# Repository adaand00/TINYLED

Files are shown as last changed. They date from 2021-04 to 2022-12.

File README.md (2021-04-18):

# TINYLED

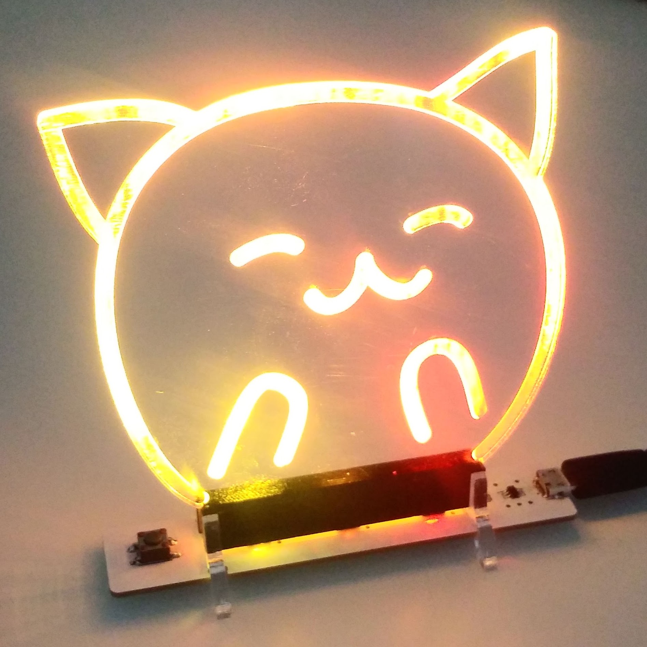
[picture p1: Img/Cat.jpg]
Image of cat sign


Light-up sign with an attiny10 and three ws2812b RGB LEDs. 

## Introduction

This is a simple project to make a light-up stand for laser-cut acrylic signs. I mainly did this as an excercise in using the attiny10-series of microcontrollers. They are very limited with just 512 or 1024 bytes of flash and 32 bytes RAM. The final code is just under 500 bytes, of which half is for driving the LEDs. 

## Circuit board

The PCB was designed in fusion360. There are test points on the underside for pogo-pin programming. The PCB also has slots for the laser cut feet to snap-fit into. 

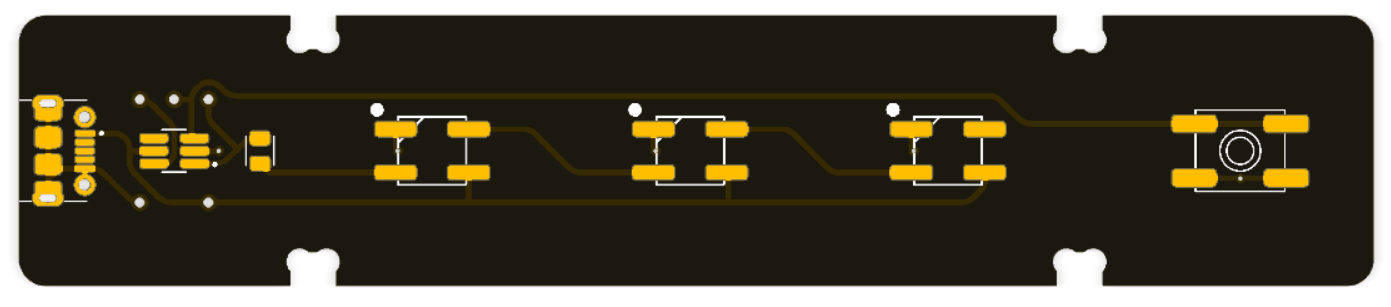
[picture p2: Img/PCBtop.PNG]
Top of PCB

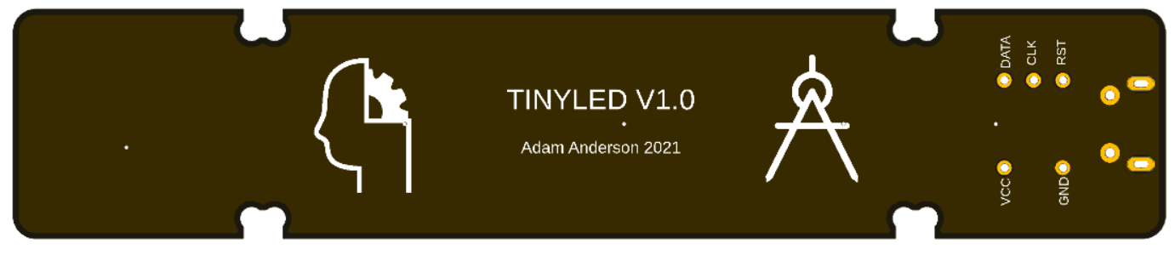
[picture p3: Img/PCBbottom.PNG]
Bottom of PCB


Gerber files are supplied in the hardware folder. 

## Programming

I used the [Attiny10IDE](https://github.com/wholder/ATTiny10IDE) by @wholder to program the chip. I managed to fit one rainbow animation and a couple solid color animations into the 512 byte memory of the attiny5. Because of space constraints, I have only implemented hue control for the LEDs. If the code was optimized a bit, brightness control could perhaps also be implemented, which would enable some more cool animations. 

The source code is provided as a .c file that can be modified and built with the attiny10IDE. There is also a .ino file that can be used to turn an arduino into a programmer.

## BOM

* 1x Attiny4/5/9/10 (tested with 5, should work with all)
* 3x ws2812b, also known as neopixels
* 1x 6x6mm tactile pushbutton with SMD mounting
* 1x 500 ohm 0603 resistor
* 1x molex 105017-0001 micro USB connector 
* 1x PCB 

## Future work

- [ ] Add brightness control in LED driver function.
- [ ] Modify PCB to allow for bigger signs (Move feet, add more LEDs, use smaller switch).
- [ ] Ditch micro USB for battery, USB-C or barrel jack.

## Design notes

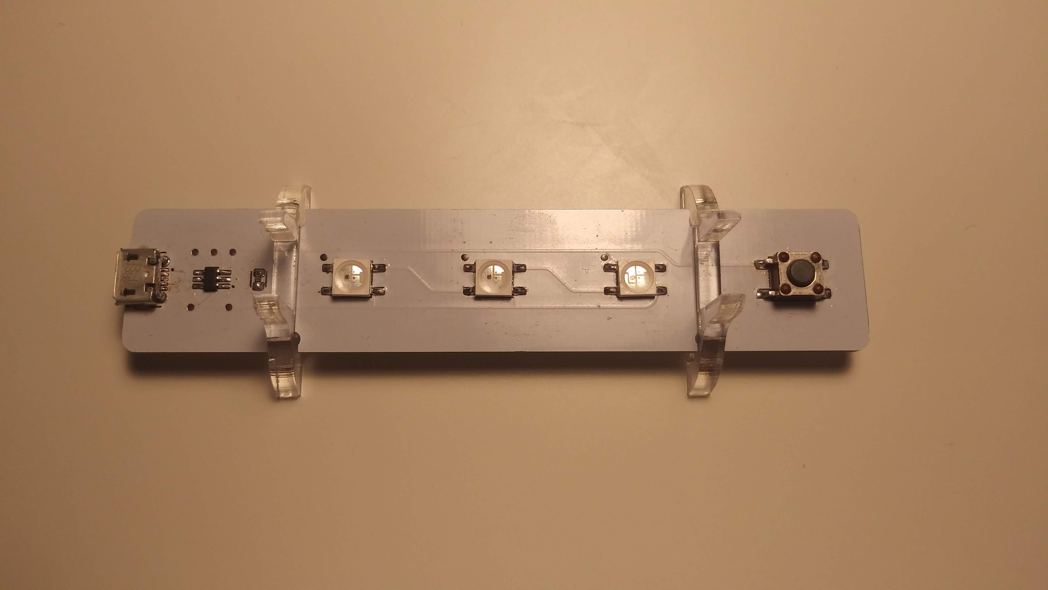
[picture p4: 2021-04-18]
Img/PCB.jpg

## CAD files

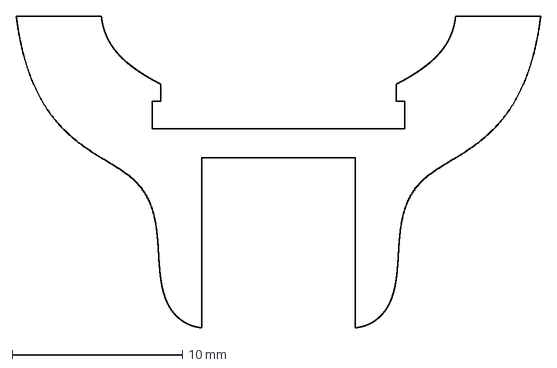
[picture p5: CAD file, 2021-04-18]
Hardware/Legs_laser.dxf
30.8 x 18.3 mm

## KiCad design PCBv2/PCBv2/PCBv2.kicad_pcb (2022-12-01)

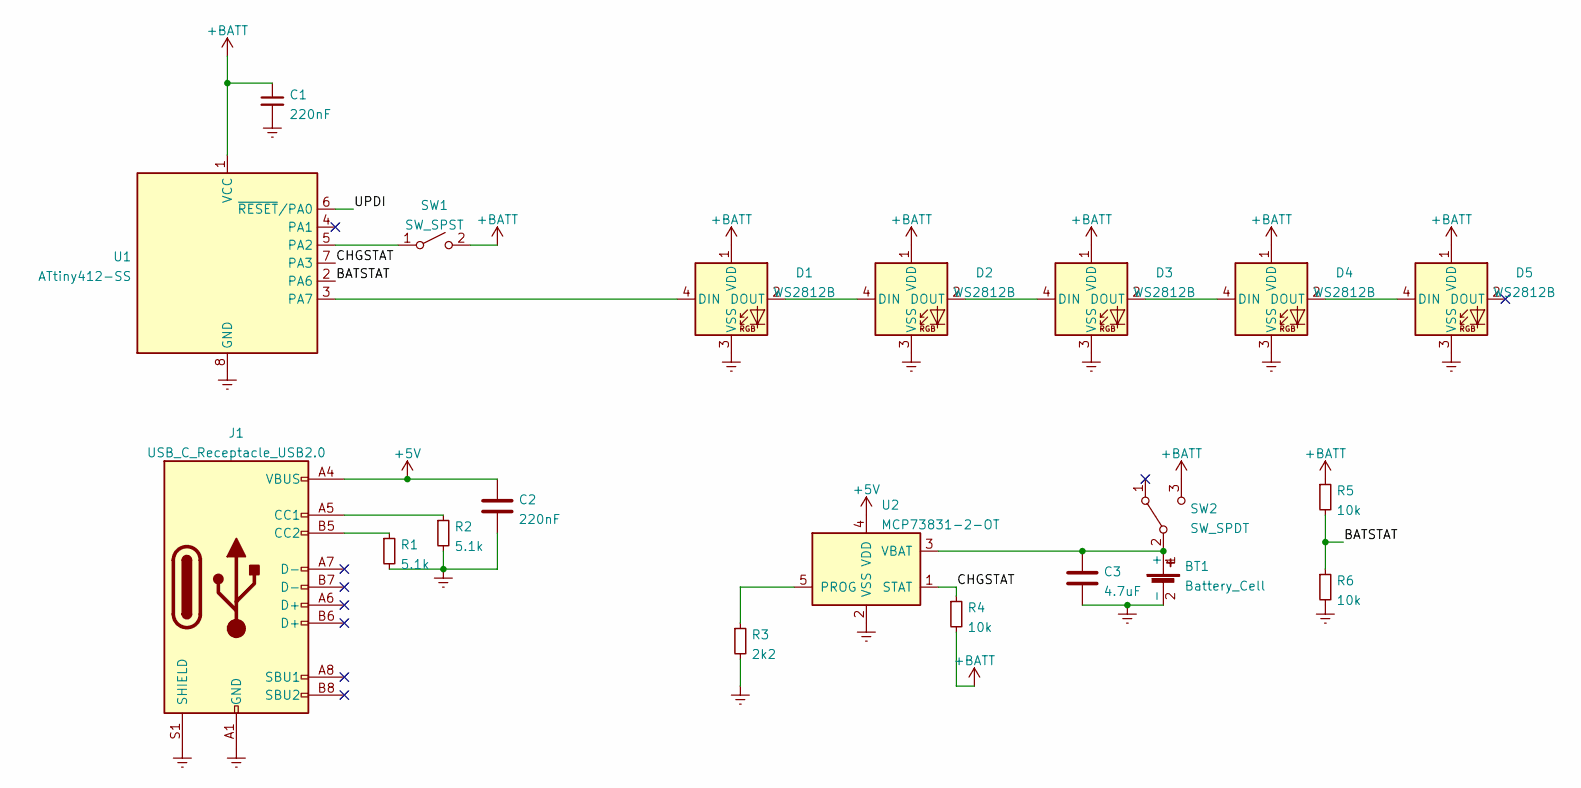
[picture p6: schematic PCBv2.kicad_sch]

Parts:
BT1: Battery_Cell; CB-18650-PC2
C1, C2: 220nF; C_0603_1608Metric_Pad1.08x0.95mm_HandSolder
C3: 4.7uF; C_1206_3216Metric_Pad1.33x1.80mm_HandSolder
D1, D2, D3, D4, D5: WS2812B; LED_WS2812B_PLCC4_5.0x5.0mm_P3.2mm
J1: USB_C_Receptacle_USB2.0; USB_C_Receptacle_HRO_TYPE-C-31-M-12
R1, R2: 5.1k; R_0603_1608Metric_Pad0.98x0.95mm_HandSolder
R3: 2k2; R_0603_1608Metric_Pad0.98x0.95mm_HandSolder
R4, R5, R6: 10k; R_0603_1608Metric_Pad0.98x0.95mm_HandSolder
SW1: SW_SPST; SW_Push_1P1T_NO_6x6mm_H9.5mm
SW2: SW_SPDT; SW_SPDT_CK-JS102011SAQN
U1: ATtiny412-SS; SOIC-8_3.9x4.9mm_P1.27mm
U2: MCP73831-2-OT; SOT-23-5

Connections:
+5V: C2.1, J1.A4 (VBUS), J1.A9 (VBUS), J1.B4 (VBUS), J1.B9 (VBUS), U2.4 (VDD)
+BATT: C1.1, D1.1 (VDD), D2.1 (VDD), D3.1 (VDD), D4.1 (VDD), D5.1 (VDD), R4.2, R5.1, SW1.2 (B), SW2.3 (C), U1.1 (VCC)
/BATSTAT: R5.2, R6.1, U1.2 (PA6)
/CHGSTAT: R4.1, U1.7 (PA3), U2.1 (STAT)
/UPDI: U1.6 (~RESET/PA0)
Earth: BT1.2 (-), C1.2, C2.2, C3.2, D1.3 (VSS), D2.3 (VSS), D3.3 (VSS), D4.3 (VSS), D5.3 (VSS), J1.A1 (GND), J1.A12 (GND), J1.B1 (GND), J1.B12 (GND), J1.S1 (SHIELD), R1.2, R2.2, R3.2, R6.2, U1.8 (GND), U2.2 (VSS)
unnamed: BT1.1 (+), C3.1, SW2.2 (B), U2.3 (VBAT)
unnamed: D1.2 (DOUT), D2.4 (DIN)
unnamed: D1.4 (DIN), U1.3 (PA7)
unnamed: D2.2 (DOUT), D3.4 (DIN)
unnamed: D3.2 (DOUT), D4.4 (DIN)
unnamed: D4.2 (DOUT), D5.4 (DIN)
unnamed: J1.A5 (CC1), R2.1
unnamed: J1.B5 (CC2), R1.1
unnamed: R3.1, U2.5 (PROG)
unnamed: SW1.1 (A), U1.5 (PA2)

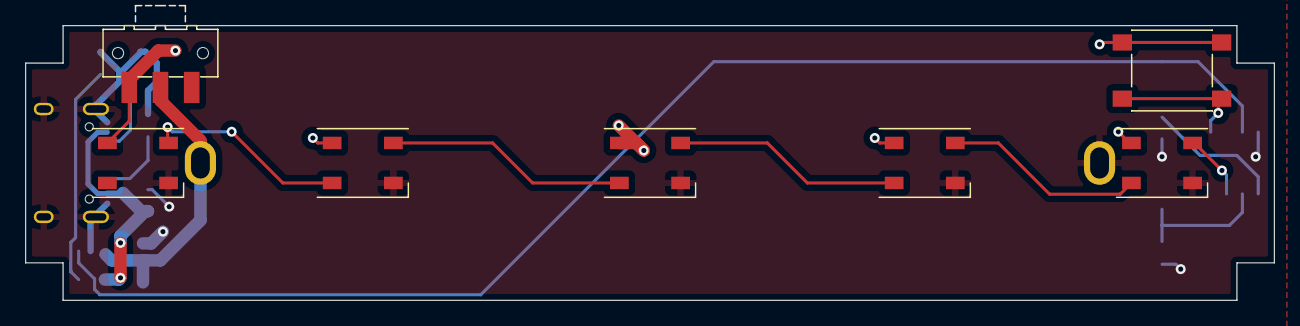
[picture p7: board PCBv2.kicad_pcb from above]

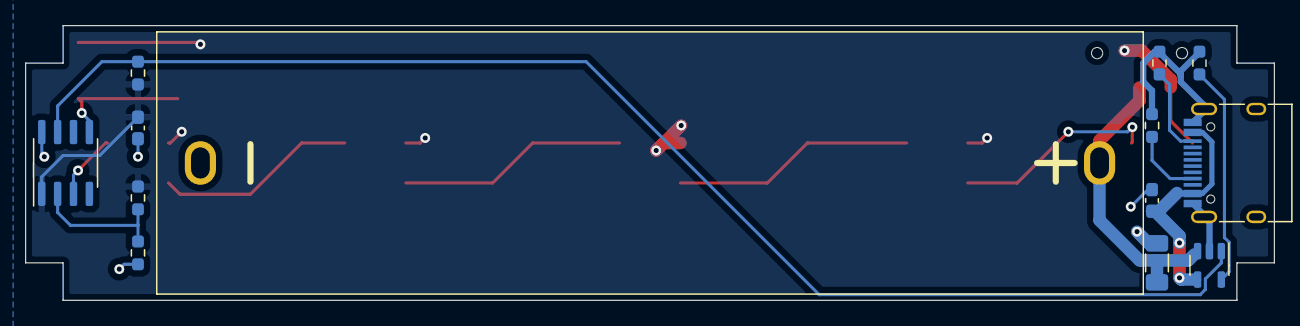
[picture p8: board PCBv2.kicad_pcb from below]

Board: 2 copper layers, 100.0 x 22.0 mm, 20 parts (13 on the bottom side), 15 nets.

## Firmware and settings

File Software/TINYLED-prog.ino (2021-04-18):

#include <avr/io.h>

/*
 * ATtiny10 TPI Generated Programmer for ATTiny10IDE.  Supports both 5V and 12V Programmers
 * IMPORTANT: Original, Relay-based Emulator/Programmer board needs mod (A0 tied to ground)
 */
 
//                 +-\/-+
//  TPIDAT / PB0 1 |    | 6 PB3 / RESET
//           Gnd 2 |    | 5 Vcc
//  TPICLK / PB1 3 |    | 4 PB2
//                 +----+

const unsigned char program[] PROGMEM  = { 
  0x14, 0xC0, 0x23, 0xC0, 0x22, 0xC0, 0x21, 0xC0, 0x20, 0xC0, 0x1F, 0xC0, 0x1E, 0xC0, 0x1D, 0xC0,
  0x1C, 0xC0, 0x1B, 0xC0, 0x1A, 0xC0, 0xA4, 0xC0, 0x9D, 0xC0, 0x9C, 0xC0, 0x9D, 0xC0, 0x9E, 0xC0,
  0x9D, 0xC0, 0x9E, 0xC0, 0x97, 0xC0, 0x96, 0xC0, 0x97, 0xC0, 0x11, 0x27, 0x1F, 0xBF, 0xCF, 0xE5,
  0xD0, 0xE0, 0xDE, 0xBF, 0xCD, 0xBF, 0x20, 0xE0, 0xA0, 0xE4, 0xB0, 0xE0, 0x01, 0xC0, 0x1D, 0x93,
  0xA6, 0x34, 0xB2, 0x07, 0xE1, 0xF7, 0x02, 0xD0, 0xBC, 0xC0, 0xDA, 0xCF, 0x48, 0xED, 0x4C, 0xBF,
  0x16, 0xBF, 0x08, 0x9A, 0x09, 0x98, 0x42, 0xE0, 0x43, 0xB9, 0x41, 0xE0, 0x41, 0xA9, 0x15, 0xA9,
  0x20, 0xE8, 0x30, 0xE0, 0x01, 0x99, 0x0A, 0xC0, 0x45, 0xA1, 0x41, 0x13, 0x08, 0xC0, 0x12, 0xA9,
  0x41, 0xA1, 0x4F, 0x5F, 0x41, 0xA9, 0x41, 0xE0, 0x45, 0xA9, 0x01, 0xC0, 0x15, 0xA9, 0x41, 0xA1,
  0x41, 0x13, 0x0C, 0xC0, 0x48, 0xE4, 0x10, 0x9A, 0x00, 0x00, 0x10, 0x98, 0x00, 0x00, 0x00, 0x00,
  0x00, 0x00, 0x00, 0x00, 0x00, 0x00, 0x41, 0x50, 0xB1, 0xF7, 0x2E, 0xC0, 0x41, 0x30, 0x51, 0xF4,
  0x42, 0xA1, 0x51, 0xE0, 0x54, 0x0F, 0x52, 0xA9, 0x5B, 0xE0, 0x54, 0x0F, 0x53, 0xA9, 0x4B, 0x5E,
  0x44, 0xA9, 0x22, 0xC0, 0x4E, 0x30, 0xF8, 0xF4, 0x42, 0x50, 0x42, 0x95, 0x40, 0x7F, 0x50, 0xA1,
  0x65, 0x2F, 0x70, 0xE0, 0x57, 0xFF, 0x06, 0xC0, 0x80, 0xE0, 0x91, 0xE0, 0x86, 0x1B, 0x97, 0x0B,
  0x68, 0x2F, 0x79, 0x2F, 0x83, 0xE0, 0x75, 0x95, 0x67, 0x95, 0x8A, 0x95, 0xE1, 0xF7, 0x74, 0x2F,
  0x76, 0x0F, 0x72, 0xA9, 0x78, 0xE0, 0x74, 0x0F, 0x73, 0xA9, 0x40, 0x5F, 0x46, 0x1B, 0x44, 0xA9,
  0x5E, 0x5F, 0x50, 0xA9, 0x01, 0xC0, 0x11, 0xA9, 0x41, 0xA1, 0x41, 0x13, 0x0A, 0xC0, 0x9F, 0xEB,
  0x44, 0xED, 0x51, 0xE0, 0x91, 0x50, 0x40, 0x40, 0x50, 0x40, 0xE1, 0xF7, 0x00, 0xC0, 0x00, 0x00,
  0xA9, 0xCF, 0xE2, 0xE4, 0xF0, 0xE0, 0xAE, 0x2F, 0xBF, 0x2F, 0x40, 0x81, 0x40, 0x3C, 0x10, 0xF0,
  0x40, 0x5C, 0x40, 0x83, 0xEF, 0x5F, 0xFF, 0x4F, 0x8C, 0x91, 0xB8, 0x2F, 0xB2, 0x95, 0xB6, 0x95,
  0xB7, 0x70, 0x88, 0x0F, 0x88, 0x0F, 0x88, 0x0F, 0x90, 0xE0, 0xA8, 0x2F, 0xA0, 0x95, 0x4B, 0x2F,
  0x49, 0x0F, 0x50, 0xE0, 0x4A, 0x30, 0x51, 0x07, 0x48, 0xF4, 0x45, 0x5F, 0x5F, 0x4F, 0x4F, 0x93,
  0x5F, 0x93, 0x08, 0x95, 0xCF, 0xEF, 0x05, 0xC0, 0xCA, 0x2F, 0x03, 0xC0, 0xC0, 0xE0, 0x01, 0xC0,
  0xC8, 0x2F, 0x40, 0xE0, 0x50, 0xE0, 0xD0, 0xE0, 0x62, 0x2F, 0x73, 0x2F, 0x04, 0x2F, 0x02, 0xC0,
  0x75, 0x95, 0x67, 0x95, 0x0A, 0x95, 0xE2, 0xF7, 0x6C, 0x23, 0x7D, 0x23, 0x67, 0x2B, 0x49, 0xF0,
  0x10, 0x9A, 0x00, 0x00, 0x00, 0x00, 0x00, 0x00, 0x00, 0x00, 0x00, 0x00, 0x10, 0x98, 0x00, 0x00,
  0x08, 0xC0, 0x10, 0x9A, 0x00, 0x00, 0x10, 0x98, 0x00, 0x00, 0x00, 0x00, 0x00, 0x00, 0x00, 0x00,
  0x00, 0x00, 0x4F, 0x5F, 0x5F, 0x4F, 0x48, 0x30, 0x51, 0x07, 0xF1, 0xF6, 0x9E, 0x5F, 0x96, 0x30,
  0x09, 0xF0, 0xC5, 0xCF, 0x85, 0xE4, 0x90, 0xE0, 0x8E, 0x17, 0x9F, 0x07, 0x09, 0xF0, 0xAB, 0xCF,
  0x9E, 0xCF, 0xF8, 0x94, 0xFF, 0xCF };
const unsigned char clockCal[] PROGMEM = {
 0x0A, 0xC0, 0x18, 0x95, 0x18, 0x95, 0x18, 0x95, 0x18, 0x95, 0x18, 0x95, 0x18, 0x95, 0x18, 0x95,
 0x18, 0x95, 0x18, 0x95, 0x18, 0x95, 0x00, 0xE0, 0x0E, 0xBF, 0x0F, 0xE5, 0x0D, 0xBF, 0x08, 0xED,
 0x0C, 0xBF, 0x00, 0xE0, 0x06, 0xBF, 0x05, 0xE9, 0x09, 0xBF, 0x0D, 0xE0, 0x01, 0xB9, 0x0D, 0xE0,
 0x02, 0xB9, 0x00, 0xE4, 0x0E, 0xBD, 0x0C, 0xE0, 0x0D, 0xBD, 0x0A, 0xE7, 0x07, 0xBD, 0x02, 0xE1,
 0x06, 0xBD, 0x18, 0xE0, 0x20, 0xE0, 0x22, 0x0F, 0x08, 0xD0, 0xD9, 0xF3, 0x00, 0x34, 0x08, 0xF0,
 0x23, 0x95, 0x1A, 0x95, 0xC1, 0xF7, 0x29, 0xBF, 0xF4, 0xCF, 0x01, 0x99, 0xFE, 0xCF, 0x01, 0xE0,
 0x01, 0x99, 0x08, 0x95, 0x03, 0x95, 0xE1, 0xF7, 0x01, 0x9B, 0xFE, 0xCF, 0x08, 0x95
};
const char          progName[] = "TINYLED.c";
const unsigned char progParms[]  = {  };
unsigned int        progSize;
unsigned char       flashMem[1024];
char                inbuf[8];
unsigned char       fuse = 0x0F;
boolean             hv1Mode = false;
boolean             hv2Mode = false;

#define  BIT_TIME  1
// Definitons for 5V Programmer
#define  VCC        2   // Pin 5 on ATtiny10
#define  TPICLK     3   // Pin 3 on ATtiny10
#define  TPIDAT     4   // Pin 1 on ATtiny10
#define  RESET      5   // Pin 6 on ATtiny10
#define  GND        6   // Pin 2 on ATtiny10
// Definitons for 12V Programmer (just different names for pins)
#define  SHDN       5   // 0 to turn on 12V, 1 to disable
#define  RELAY      6   // 1 to program, 0 to emulate
// Definitions for pins used to detect HV programmers
#define  HV1_DETECT A0  // Is LOW if HV Programmer (version 1, 2x DPDT relays)
#define  HV2_DETECT A1  // Is LOW if HV Programmer (version 2, 4 ch analog switch)

// Define IO Registers
#define  NVMCMD  0x33
#define  NVMCSR  0x32

// Define NVM Commands
#define  NO_OPERATION  0x00
#define  CHIP_ERASE    0x10
#define  SECTION_ERASE 0x14
#define  WORD_WRITE    0x1D

void setup () {
  // Check for HV Progammerw (HV1_DETECT or HV2_DETECT pin is LOW)
  pinMode(HV1_DETECT, INPUT_PULLUP);
  pinMode(HV2_DETECT, INPUT_PULLUP);
  delay(10);
  hv1Mode = digitalRead(HV1_DETECT) == LOW;
  hv2Mode = digitalRead(HV2_DETECT) == LOW;
  // Set flashMem to unprogrammed value and then copy program code into it
  memset(flashMem, 0xFF, sizeof(flashMem));
  memcpy_P(flashMem, program, sizeof(program));
  progSize = sizeof(program);
  Serial.begin(115200);
  disablePins();
  if (hv1Mode || hv2Mode) {
    pinMode(SHDN, OUTPUT);        // Connect SHDN
    if (hv1Mode) {
        digitalWrite(SHDN, HIGH); // 12v off
    } else {
        digitalWrite(SHDN, LOW);  // 12v off
    }
    pinMode(RELAY, OUTPUT);       // Connect RELAY
    digitalWrite(RELAY, LOW);     // Chip in Emulate mode (Relay Off)
    Serial.print("\x06\x06");     // Send ACK ACK sequence tp signal ready
  } else {
    pinMode(GND, OUTPUT);         // Connect GND
    digitalWrite(GND, LOW);       // GND Always Low
    if (sizeof(program) > 0) {
      printInstructions();
    } else {
      Serial.print("\x06\x06");   // Send ACK ACK sequence tp signal ready
    }
  }
}

void enablePins () {
  if (hv1Mode || hv2Mode) {
    digitalWrite(RELAY, HIGH);    // Chip in Program mode (Relay On)
    delay(200);
  }
  pinMode(VCC, OUTPUT);           // Connect VCC
  digitalWrite(VCC, LOW);         // VCC off
  pinMode(TPICLK, OUTPUT);        // Connect TPICLK
  digitalWrite(TPICLK, HIGH);     // Clk high
  pinMode(TPIDAT, INPUT);         // Connect TPIDAT
  digitalWrite(TPIDAT, HIGH);     // Enable pullup
  delay(10);
  if (!hv1Mode && !hv2Mode) {
    pinMode(RESET, OUTPUT);       // Connect RESET
    digitalWrite(RESET, HIGH);    // RESET Off
  }
  delay(200);
}

void disablePins () {
  pinMode(TPICLK, INPUT);       // Disconnect TPICLK
  pinMode(TPIDAT, INPUT);       // Disconnect TPIDAT
  pinMode(VCC, INPUT);          // Disconnect VCC
  digitalWrite(TPICLK, LOW);    // No pull up
  digitalWrite(TPIDAT, LOW);    // No pull up
  digitalWrite(VCC, LOW);       // No pull up
  if (hv1Mode || hv2Mode) {
    digitalWrite(RELAY, LOW);   // Chip in Emulate mode
  } else {
    pinMode(RESET, INPUT);      // Disconnect RESET
    digitalWrite(RESET, LOW);   // No pull up
  }
  delay(200);
}

void pulseClock () {
  digitalWrite(TPICLK, LOW);
  delayMicroseconds(BIT_TIME);
  digitalWrite(TPICLK, HIGH);
  delayMicroseconds(BIT_TIME);
}

void sendFrame (unsigned char data) {
  unsigned char tmp = data;
  // Write start bit
  pinMode(TPIDAT, OUTPUT);
  digitalWrite(TPIDAT, LOW);
  pulseClock();
  unsigned char check = 0;
  // Write data bits
  for (unsigned char ii = 0; ii < 8; ii++) {
    digitalWrite(TPIDAT, tmp & 1);
    check ^= tmp & 1;
    tmp >>= 1;
    pulseClock();
  }
  // Write check bit
  digitalWrite(TPIDAT, check);
  pulseClock();
  // Write stop bits
  digitalWrite(TPIDAT, HIGH);
  pulseClock();
  pinMode(TPIDAT, INPUT);
  pulseClock();
}

unsigned char readBit () {
  digitalWrite(TPICLK, LOW);
  delayMicroseconds(BIT_TIME);
  unsigned char data = digitalRead(TPIDAT) ? 1 : 0;
  digitalWrite(TPICLK, HIGH);
  delayMicroseconds(BIT_TIME);
  return data;
}

unsigned char readFrame () {
  pinMode(TPIDAT, INPUT);
  for (int ii = 0; ii < 256; ii++) {
    if (readBit() == 0) {
      // Start bit found
      unsigned char data = 0;
      unsigned char check = 0;
      for (unsigned char jj = 0; jj < 8; jj++) {
        unsigned char tmp = readBit();
        data >>= 1;
        data |= tmp != 0 ? 0x80 : 0x00;
        check ^= tmp & 1;
      }
      unsigned char tmp = readBit();
      readBit();
      readBit();
      if (tmp == check) {
        return data;
      }
      return 0xFF;
    }
  }
  Serial.println(F("Read timeout"));
  // Timeout, or error
  return 0xFF;
}

unsigned char enterProgMode () {
  sendFrame(0xE0);              // SKEY Opcode
  sendFrame(0xFF);              // Send 8 Byte Key
  sendFrame(0x88);
  sendFrame(0xD8);
  sendFrame(0xCD);
  sendFrame(0x45);
  sendFrame(0xAB);
  sendFrame(0x89);
  sendFrame(0x12);
  for (unsigned char ii = 0; ii < 100; ii++) {
    if ((readCtlSpace(0x00) & 0x02) != 0) {
      return 1;  // enabled
    }
  }
  Serial.println(F("Unable to select program mode"));
  return 0;      // timeout
}

void setPointerReg (unsigned int add) {
  sendFrame(0x68);          // SSTPR 0
  sendFrame(add & 0xFF);
  sendFrame(0x69);          // SSTPR 1
  sendFrame(add >> 8);
}

unsigned char readAndInc () {
  sendFrame(0x24);          // SLD++
  return readFrame();
}

void writeAndInc (unsigned char data) {
  sendFrame(0x64);          // SST++
  sendFrame(data);
}

unsigned char readIoSpace (unsigned char add) {
  sendFrame(0x10 | ((add & 0x30) << 1) | (add & 0x0F));  // SIN
  return readFrame();
}

void writeIoSpace(unsigned char add, unsigned char data) {
  sendFrame(0x90 | ((add & 0x30) << 1) | (add & 0x0F));  // SOUT
  sendFrame(data);
}

unsigned char readCtlSpace (unsigned char add) {
  sendFrame(0x80 | (add & 0x0F));   // SLDCS
  return readFrame();
}

void nvmWait () {
  while ((readIoSpace(0x32) & 0x80) != 0) {
    delay(BIT_TIME);    // Arbitrary delay
  }
}

boolean powerOn () {
  enablePins();
  digitalWrite(VCC, HIGH);        // VCC on
  delay(128);                     // Wait 128 ms
  if (hv1Mode) {
    digitalWrite(SHDN, LOW);      // 12v On
  } else if (hv2Mode) {
    digitalWrite(SHDN, HIGH);     // 12v On
  } else {
    digitalWrite(RESET, LOW);     // RESET On
  }
  delay(10);                      // Wait 10 ms
  digitalWrite(TPIDAT, HIGH);     // Data high
  pinMode(TPIDAT, OUTPUT);
  for (unsigned char ii = 0; ii < 32; ii++) {
    pulseClock();
  }
  return true;
}

void powerOff () {
  if (hv1Mode) {
    digitalWrite(SHDN, HIGH);     // 12v Off
  } else if (hv2Mode) {
    digitalWrite(SHDN, LOW);      // 12v Off
  } else {
    digitalWrite(RESET, HIGH);    // RESET Off
  }
  delay(128);                     // Wait 128 ms
  digitalWrite(VCC, LOW);         // VCC off
  disablePins();
}

/*
 *  0x1E, 0x8F, 0x0A  ATtiny4
 *  0x1E, 0x8F, 0x09  ATtiny5
 *  0x1E, 0x90, 0x08  ATtiny9
 *  0x1E, 0x90, 0x03  ATtiny10
 */
boolean printSignature () {
  if (powerOn()) {
    if (enterProgMode()) {
      // Read device signature
      Serial.println();
      Serial.print(F("Device: "));
      setPointerReg(0x3FC0);        // Device Id Bytes
      unsigned char sig[3];
      for (unsigned char ii = 0; ii < 3; ii++) {
        if (ii > 0) {
          Serial.print(", ");
        }
        printHex(sig[ii] = readAndInc());
      }
      if (sig[0] == 0x1E) {
        if (sig[1] == 0x8f) {
          if (sig[2] == 0x0A) {
            Serial.println(F(" - ATTiny4"));
          } else if (sig[2] == 0x09) {
            Serial.println(F(" - ATTiny5"));
          }
        } else if (sig[1] == 0x90) {
          if (sig[2] == 0x08) {
            Serial.println(F(" - ATTiny9"));
          } else if (sig[2] == 0x03) {
            Serial.println(F(" - ATTiny10"));
          }
        }
      }
      Serial.println();
    }
    powerOff();
    return true;
  } else {
    powerOff();
    return false;
  }
}

// Read 1 second half cycle signal on TPIDAT Input
void measureClock () {
  enablePins();
  digitalWrite(VCC, HIGH);      // VCC on
  delay(200);
  boolean state, lState = digitalRead(TPIDAT);
  unsigned char hi = 0xFF, lo = 0x00, mid = 0x80, sel;
  long lowest = 1000000;
  // Verify TPIDAT signal is changing before measuring time interval
  unsigned long timeout = millis();
  Serial.print(F("Measuring Clock."));
  do {
    // Must see TPIDAT change within 2 seconds, or timeout
    if ((millis() - timeout) > 2000) {
      Serial.println(F("Timeout"));
      powerOff();
      return;
    }
    state = digitalRead(TPIDAT);
  } while (state == lState);
  do {
    setClockTweak(mid);
    delay(1000);
    do {
      state = digitalRead(TPIDAT);
    } while (state == lState);
    long sTime = micros();
    lState = state;
    do {
      state = digitalRead(TPIDAT);
    } while (state == lState);
    long eTime = micros();
    lState = state;
    long diff = eTime - sTime;
    Serial.print(".");
    if (diff < 1000000) {
      hi = mid;
    } else {
      lo = mid;
    }
    if (diff < lowest) {
      lowest = diff;
      sel = mid;
    }
    mid = (hi + lo) / 2;
  } while (abs(hi - lo) > 1);
  Serial.print(F("\nRecommended Clock Offset: 0x"));
  Serial.println(mid, HEX);
  digitalWrite(VCC, LOW);       // VCC off
  disablePins();
}

void setClockTweak (unsigned char val) {
  digitalWrite(TPICLK, LOW);        // Short Pulse
  delayMicroseconds(1000);
  digitalWrite(TPICLK, HIGH);
  delay(1);
  for (int ii = 0; ii < 8; ii++) {
    int width = (val & 0x80) != 0 ? 80 : 20;
    val = val << 1;
    digitalWrite(TPICLK, LOW);      // Short Pulse
    delayMicroseconds(width);
    digitalWrite(TPICLK, HIGH);
    delay(1);
  }
}

void printFuse () {
  if (powerOn()) {
    if (enterProgMode()) {
      // Read device signature
      Serial.print(F("Fuse:  "));
      setPointerReg(0x3F40);        // Configuration Byte
      printHex(readAndInc());
      Serial.println();
    }
  }
  powerOff();
}

void writeFlash (unsigned char fuseByte) {
  if (powerOn()) {
    if (enterProgMode()) {
      Serial.print(F("\nProgramming Flash and Fuse"));
      // Erase all flash bytes
      writeIoSpace(NVMCMD, CHIP_ERASE);
      setPointerReg(0x4001);
      writeAndInc(0x00);    // Write dummy high byte
      nvmWait();
      writeIoSpace(NVMCMD, NO_OPERATION);
      nvmWait();
      // Erase Config Section
      writeIoSpace(NVMCMD, SECTION_ERASE);
      setPointerReg(0x3F41);
      writeAndInc(0x00);    // Write dummy high byte
      nvmWait();
      writeIoSpace(NVMCMD, NO_OPERATION);
      nvmWait();
      // Write config byte (Note: bits are inverted, so '0' value is ON)
      writeIoSpace(NVMCMD,WORD_WRITE);
      setPointerReg(0x3F40);
      writeAndInc(fuseByte | 0xF8);    // Config Byte
      writeAndInc(0xFF);
      writeIoSpace(NVMCMD, NO_OPERATION);
      nvmWait();
      // Write program to flash memory
      writeIoSpace(NVMCMD,WORD_WRITE);
      setPointerReg(0x4000);
      for (int ii = 0; ii < progSize; ii += 2) {
        writeAndInc(flashMem[ii]);      // Low byte
        writeAndInc(flashMem[ii + 1]);  // High byte
        nvmWait();
        if ((ii & 0x0F) == 0) {
          Serial.print(".");
        }
      }
      writeIoSpace(NVMCMD, NO_OPERATION);
      nvmWait();
      Serial.print(F("Done - "));
      Serial.print(progSize, DEC);
      Serial.println(F(" bytes written"));
      Serial.print(F("Fuse byte set to: "));
      printHex(fuseByte);
      Serial.println();
    }
  }
  powerOff();
}

void writeFuse (unsigned char fuseByte) {
  if (powerOn()) {
    if (enterProgMode()) {
      // Erase Config Section
      writeIoSpace(NVMCMD, SECTION_ERASE);
      setPointerReg(0x3F41);
      writeAndInc(0x00);    // Write dummy high byte
      nvmWait();
      writeIoSpace(NVMCMD, NO_OPERATION);
      nvmWait();
      // Write config byte (Note: bits are inverted, so '0' value is ON)
      writeIoSpace(NVMCMD,WORD_WRITE);
      setPointerReg(0x3F40);
      writeAndInc(fuseByte | 0xF8);    // Config Byte
      writeAndInc(0xFF);
      writeIoSpace(NVMCMD, NO_OPERATION);
      nvmWait();
      Serial.print(F("Fuse byte set to: "));
      printHex(fuseByte);
      Serial.println();
    }
  }
  powerOff();
}
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
void loop () {
  while (true) {
    if (Serial.available() > 0) {
      unsigned char cc = toupper(Serial.read());
      switch (cc) {
        case 'I':
          // Identify connected ATtiny device
          printSignature();
          break;
        case 'C':
          // Change exported parameters
          if (progParms != 0 && sizeof(progParms) > 0) {
            delay(200);
            while (Serial.available()) {
              Serial.read();
            }
            Serial.println(F("\nType <new> + enter to change, else enter:"));
            byte ii = 0;
            byte state = 0;
            unsigned int add;
            unsigned char cc;
            unsigned int val;
            while (ii < sizeof(progParms)) {
              switch (state) {
                case 0:
                  cc = progParms[ii++];
                  if (cc == 0) {
                    state++;
                  } else {
                    Serial.write(cc);
                  }
                  break;
                case 1:
                  byte size = progParms[ii++];
                  add = (unsigned int) progParms[ii++] << 8;
                  add |= progParms[ii++];
                  Serial.print(" = ");
                  if (size == 2) {
                    val = flashMem[add + 1] << 8 + flashMem[add];
                  } else if (size == 1) {
                    val =  flashMem[add];
                  }
                  Serial.print(val, DEC);
                  Serial.print(" ?");
                  if (getString() > 0) {
                    val = readDecimal();
                    Serial.print(F(" Changed to "));
                    Serial.println(val, DEC);
                    if (size == 2) {
                      flashMem[add] = val & 0xFF;
                      flashMem[add + 1] = val >> 8;
                    } else if (size == 1) {
                      flashMem[add] = val;
                    }
                  } else {
                    Serial.println(F(" Unchanged"));
                  }
                  state = 0;
                  break;
              }
            }
            Serial.println(F("Done"));
          }
          break;
        case 'P':
          // Program ATtiny
          writeFlash(fuse);
          break;
        case'D':
          download();
          break;
        case '?':
          printInstructions();
          break;
        case 'M':
          measureClock();
          break;
        case 'K':
          memset(flashMem, 0xFF, sizeof(flashMem));
          memcpy_P(flashMem, clockCal, sizeof(clockCal));
          progSize = sizeof(clockCal);
          writeFlash(0x0B);
          measureClock();
          // Restore built-in program
          memset(flashMem, 0xFF, sizeof(flashMem));
          memcpy_P(flashMem, program, sizeof(program));
          progSize = sizeof(program);
          break;
        case 'S':
          printSignature();
          break;
        case 'F':
          printFuse();
          break;
        case 'V':
          pinMode(VCC, OUTPUT);
          digitalWrite(VCC, HIGH);      // VCC on
          Serial.println(F("VCC on"));
          break;
        case 'X':
          digitalWrite(VCC, LOW);       // VCC off
          pinMode(VCC, INPUT);
          Serial.println(F("VCC off"));
          break;
        case 'T':
          if (hv1Mode) {
            Serial.print(F("hv1Mode\n"));
          } else if (hv2Mode) {
            Serial.print(F("hv2Mode\n"));
          } else {
            Serial.print(F("Non HV\n"));
          }
          break;
        case '*':
          Serial.write(0x1B);           // Respond with ESC code
          break;
      }
    }
  }
}

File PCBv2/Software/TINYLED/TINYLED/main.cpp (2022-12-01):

/* maxhue = 192 */

#include <avr/io.h>
#include <util/delay.h>


#define W_ONE __asm__ __volatile__ ( \
"sbi 0x02,0" "\n\t"\
"nop" "\n\t"\
"nop" "\n\t"\
"nop" "\n\t"\
"nop" "\n\t"\
"nop" "\n\t"\
"cbi 0x02,0" "\n\t"\
"nop" "\n\t"::\
)

#define W_ZERO __asm__ __volatile__ ( \
"sbi 0x02,0" "\n\t"\
"nop" "\n\t"\
"cbi 0x02,0" "\n\t"\
"nop" "\n\t"\
"nop" "\n\t"\
"nop" "\n\t"\
"nop" "\n\t"\
"nop" "\n\t"::\
)

#define NUM_PIX 5

#define PIX_PIN_A 1
#define BAT_PIN_A 0
#define CHG_PIN_B 3
#define BTN_PIN_B 1

typedef unsigned char uint8_t;

void pix();

uint8_t hue[NUM_PIX];
uint8_t state;
uint8_t phase;
bool pressed;

void setup(){
	
	// Outputs
	DDRA = 1<< PIX_PIN_A;
	DDRB = 1<< BTN_PIN_B
	
	
	
	state = 1;
	pressed = 0;
}

void loop(){
	
	if(digitalRead(BTN_PIN) == 0){
		if(!pressed){
			hue[0] = 0;
			
			state++;
			pressed = true;
		}
		}else{
		pressed = false;
	}

	if(state == 0){

		for(uint8_t i = 0; i<24*NUM_PIX; i++){
			W_ZERO;
		}

		} else if (state == 1) {

		hue[0]++;
		hue[1] = hue[0] + 10;
		hue[2] = hue[1] + 10;

		} else if (state < 14){

		uint8_t h = (state-2) << 4;
		uint8_t add;
		if(phase<128){
			add = phase>>3;
			}else{
			add = (256-phase)>>3;
		}
		hue[0] = h + add;
		hue[1] = h + 8;
		hue[2] = h + 16 - add;
		phase += 2;

		} else {
		state = 0;
	}

	if(state){
		pix();
	}

	delay(75);
}


inline void pix(){
	for(uint8_t i=0; i<NUM_PIX; i++){
		
		if(hue[i]>=192){
			hue[i] -= 192;
		}

		uint8_t area = hue[i]>>5;
		uint8_t ang = ((0b00011111) & hue[i])<<3;

		for(uint8_t c = 0; c<3; c++){
			uint8_t out;
			
			switch(area){
				case 0: case 6:
				out = ang;
				break;

				case 1: case 2: case 7: case 8:
				out = 255;
				break;

				case 3: case 9:
				out = 255-ang;
				break;

				default:
				out = 0;
				break;
			}
			
			area += 2;

			for(uint8_t b=0; b<8; b++){
				if(out & 0x80>>b){
					W_ONE;
					} else {
					W_ZERO;
				}
			}
		}

	}
}

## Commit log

2021-04-18 Added project files
    [Legs_laser.dxf]
2021-04-18 Added images of PCB
2022-06-15 start on PCB v2
    [PCBv2.kicad_pcb, PCBv2.kicad_sch]
2022-12-01 v2 Updates, not tested yet
    [PCBv2-B_Cu.gbr, PCBv2-B_Mask.gbr, PCBv2-B_Paste.gbr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]
